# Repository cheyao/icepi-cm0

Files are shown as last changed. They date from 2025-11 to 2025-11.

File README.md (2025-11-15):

# Icepi CM0

A low-cost carrier board for the H3 CPU. It let's you have a cheap yet powerful Linux/Android device on your hand.



## Features

- H3 Processor
    - Quad-Core ARM Cortex-A7 @ 1.296GHz
    - ARM Mali400 MP2 OpenGL ES 2.0
- 512MiB of DDR3 RAM
- Ethernet PHY
- WiFi & Bluetooth
- GPDI
- Raspberry-pi compatiable GPIO
- USB connectors:
    - 2x USB-A 
    - 2x USB-C with one OTG
    - 1x USB-C 100W PD
- 3.5mm audio jack
- SD card slot
- eMMC 5.1 storage



More info coming soon!

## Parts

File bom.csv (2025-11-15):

Item | Price | Link
PCB + PCBA | 463.24$ | https://jlcpcb.com/
Heatsink | 6.74$ | https://fr.aliexpress.com/item/1005009710858892.html
Total | 469.98$

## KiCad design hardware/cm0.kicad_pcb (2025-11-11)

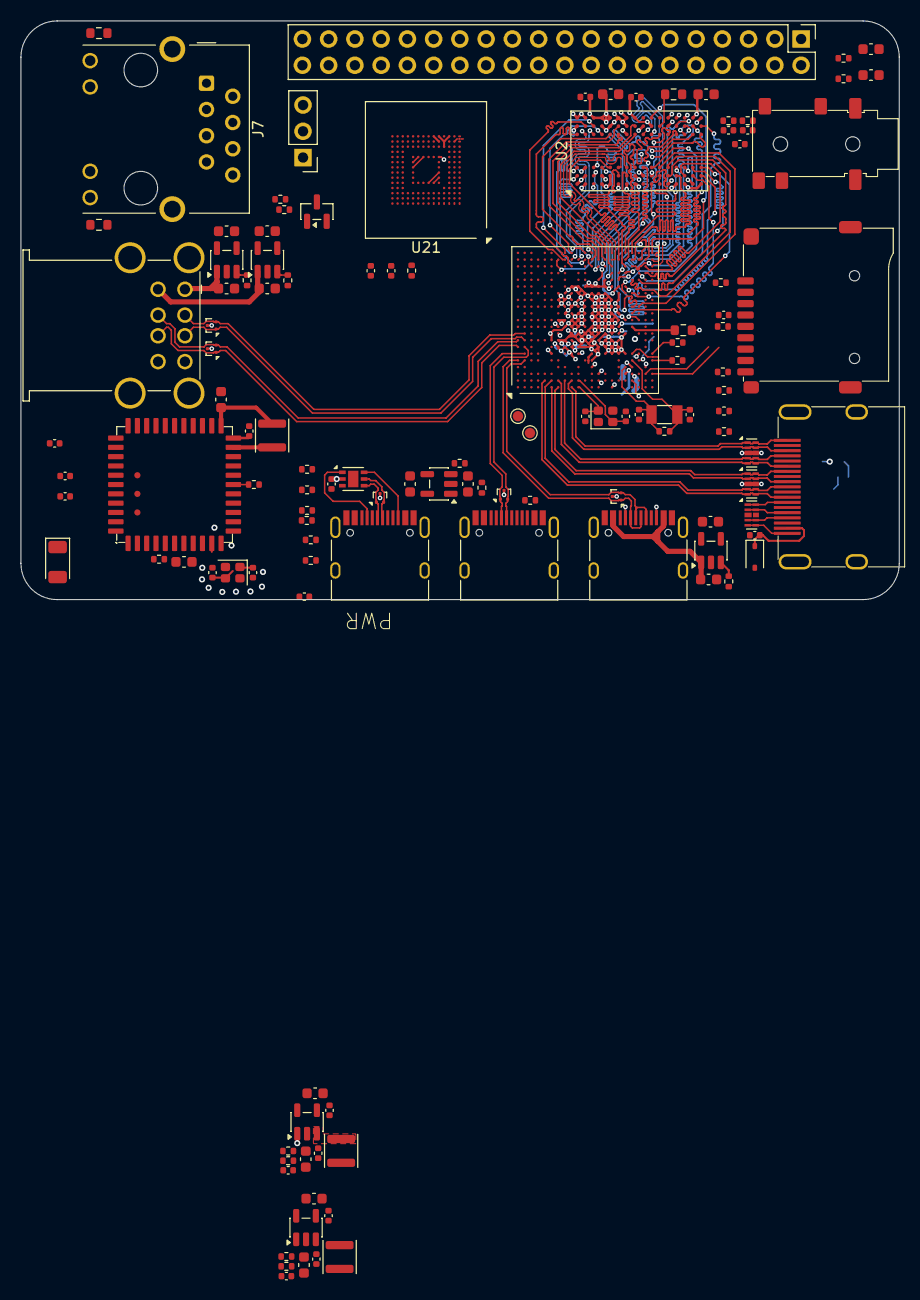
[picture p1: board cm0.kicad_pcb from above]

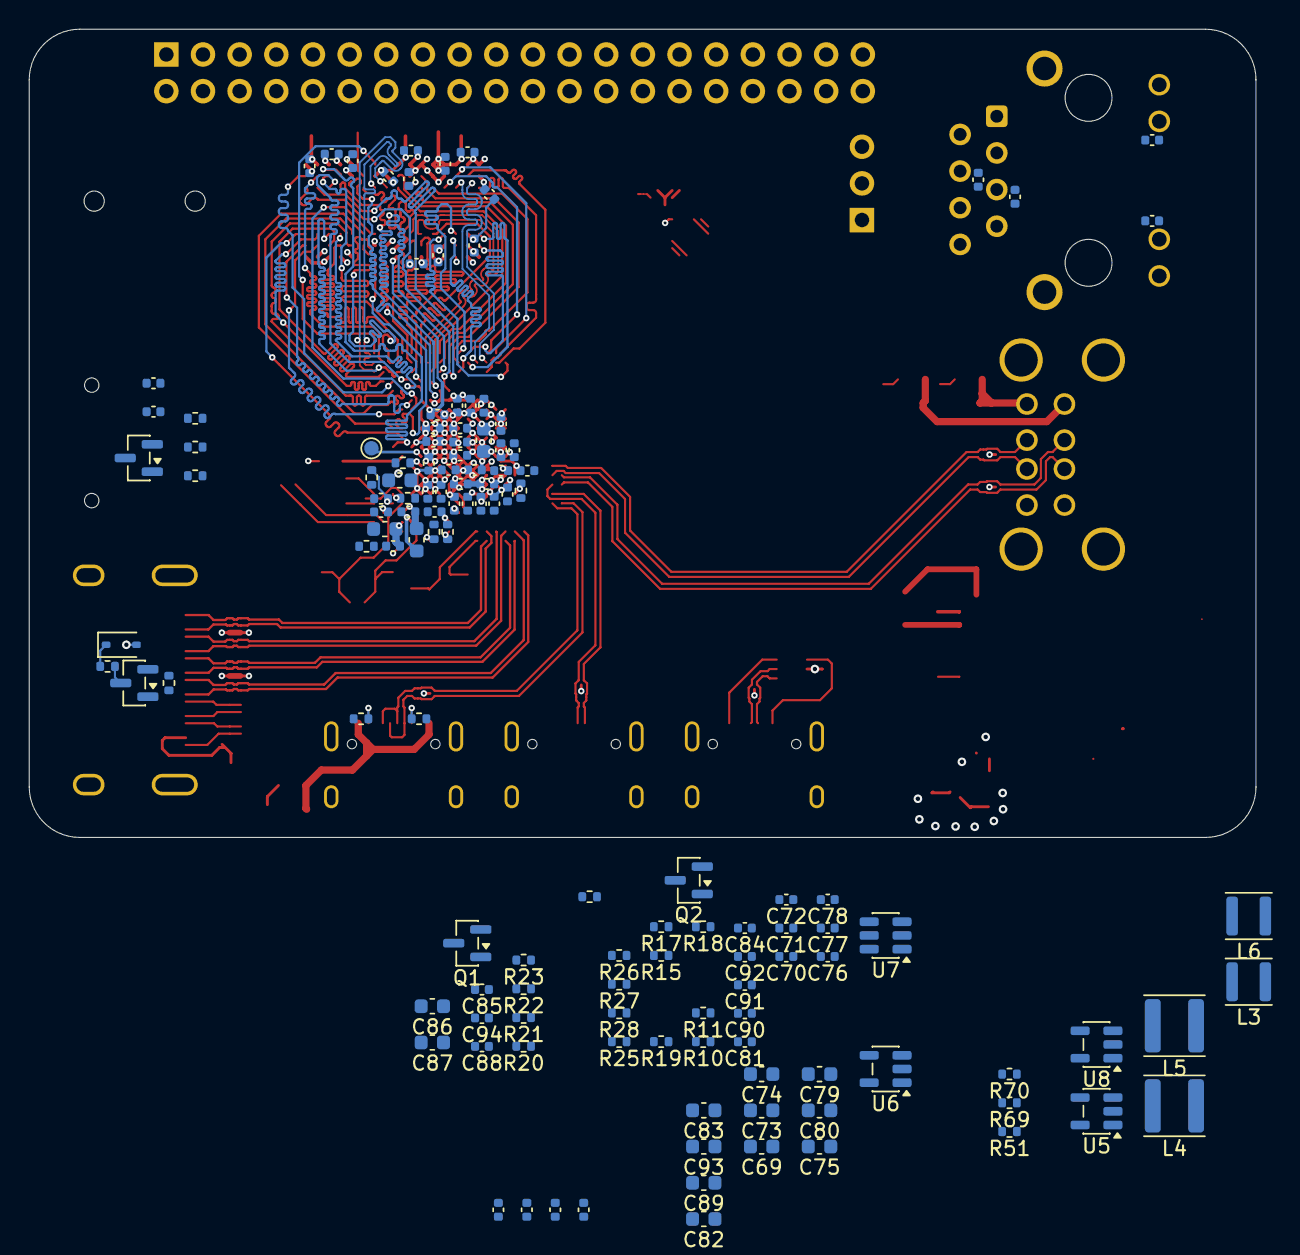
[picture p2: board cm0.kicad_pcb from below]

Board: 4 copper layers, 85.0 x 56.0 mm, 252 parts (129 on the bottom side), 209 nets.

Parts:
AE1: 2450AT18A100E; Johanson_2450AT18x100
C1, C2, C3, C4, C7, C8, C9, C12, C14, C18, C19, C23, C24, C26, C27, C29, C31, C37, C38, C40, C41, C42, C43, C46, C47, C48, C49, C52, C53, C54, C55, C56, C57, C58, C60, C62, C65, C67, C70, C72, C76, C78, C81, C84, C85, C90, C92, C95, C98, C101, C104, C108, C110, C113, C114, C121, C122, C123, C124, C130: 100nF; C_0402_1005Metric
C10, C11, C32, C129: 4.7uF; C_0402_1005Metric
C13, C16, C17, C21, C22, C25, C33, C35, C36, C45, C51, C107, C109, C111: 1uF; C_0402_1005Metric
C15, C20, C28, C30, C44, C50, C63, C64, C68, C69, C73, C74, C79, C83, C86, C89, C96, C97, C99, C100, C102, C103, C105, C106, C112, C118, C125, C126: 10uF; C_0603_1608Metric
C34, C39, C127, C128: 15pF; C_0402_1005Metric
C59, C75, C80, C82, C87, C93: 22uF; C_0603_1608Metric
C61, C66, C71, C77, C88, C91: 22pF; C_0402_1005Metric
C94, C116, C117: NC; C_0402_1005Metric
C115, C119, C120: 10pF; C_0402_1005Metric
D1, D2: 1N5819WS; D_SOD-323
J1: USB_A_Stacked; USB_A_SHOUHAN_AF_SS-JB17.6_Horizontal_Stacked
J2, J3, J4: USB_C_Receptacle_USB2.0_14P; USB_C_Receptacle_HRO_TYPE-C-31-M-12
J5: GPDI_A; GPDI_A_XUNPU_001S
J6: Micro_SD_Card_Det1; microSD_TF-01A
J7: RJ45_Hanrun_HR913550A_Horizontal; RJ45_Hanrun_HR911105A_Horizontal
J8: Conn_01x03; PinHeader_1x03_P2.54mm_Vertical
J9: Conn_02x20_Odd_Even; PinHeader_2x20_P2.54mm_Vertical
J10: AudioJack_PJ-342; Jack_3.5mm_SHOUHAN_PJ-342
L1, L2, L3, L6, L7: 2.2uH; L_Sunlord_SWPA3015S
L4, L5: 2.2uH; L_Sunlord_SWPA4030S
Q1, Q3, Q4: BSN20; SOT-23
Q2: AO3415A; SOT-23
Q5: MMBT3904; SOT-23
R1: 6.04k; R_0402_1005Metric
R2, R9, R54, R55: 240; R_0603_1608Metric
R3, R5, R24: 0; R_0402_1005Metric
R4: 220k; R_0402_1005Metric
R6: 10M; R_0402_1005Metric
R7, R8, R39, R40: 2k; R_0402_1005Metric
R10, R11, R12, R15, R16, R20, R23, R25, R31, R32, R33, R36, R41, R45, R51, R56, R63, R64, R65: 10k; R_0402_1005Metric
R13, R17, R26: 2.2k; R_0402_1005Metric
R14: 15k; R_0402_1005Metric
R18, R19, R27, R52, R62, R69, R70: 100k; R_0402_1005Metric
R21: 11.8K; R_0402_1005Metric
R22, R28, R37, R38, R46, R47, R48, R49, R50: 33k; R_0402_1005Metric
R29, R30, R34, R35, R42, R43: 56k; R_0402_1005Metric
R44, R53, R57, R58, R59, R60: 33; R_0402_1005Metric
R61, R66, R67, R68: 47k; R_0402_1005Metric
TP1, TP2, TP3: TestPoint; TestPoint_Pad_D1.0mm
U1: H3; FBGA-347_14x14mm_Layout21x21_P0.65mm
U2: H5TQ4G63EFR; FBGA-96_7.5x13mm_Layout9x16_P0.8mm
U3, U4, U5, U8: SY8088; SOT-23-5
U6: SY8089A; SOT-23-5
U7: SY8113; TSOT-23-6
U9, U10, U11, U12: SY6280AAC; SOT-23-5
U13, U14, U15, U16, U18: TPD2EUSB30; Texas_DRT-3
U17: HUSB237; DFN-6-1EP_2x2mm_P0.65mm_EP1x1.6mm
U19, U20, U23: UCL0524P; Diodes_UDFN-10_1.0x2.5mm_P0.5mm
U21: EMMC5.1_BGA153; LFBGA-153_11.5x13mm_Layout14x14_P0.5mm
U22: AP6212
Y1: 32kHz; Crystal_SMD_3215-2Pin_3.2x1.5mm
Y2: 26MHz; Crystal_SMD_2016-4Pin_2.0x1.6mm
Y3: 24MHz; Crystal_SMD_2016-4Pin_2.0x1.6mm

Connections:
+1V1_CPUX: C15.1, C16.2, C17.2, C18.2, C19.2, C85.2, C86.1, C87.1, L5.2, U1.N8 (VDD-CPUX), U1.P6 (VDD-CPUX), U1.P7 (VDD-CPUX), U1.P8 (VDD-CPUX), U1.P9 (VDD-CPUX), U1.R6 (VDD-CPUX), U1.R7 (VDD-CPUX), U1.R8 (VDD-CPUX), U1.T6 (VDD-CPUX), U1.T7 (VDD-CPUX), U1.T8 (VDD-CPUX), U1.U6 (VDD-CPUX), U1.U9 (VDD-CPUX)
+1V2_SYSTEM: C4.2, C20.1, C21.2, C22.2, C23.2, C24.2, C77.1, C78.2, C79.1, C80.1, L4.2, R18.2, U1.F8 (EPHY_VDD), U1.H10 (VDD-SYS), U1.J10 (VDD-SYS), U1.J11 (VDD-SYS), U1.J12 (VDD-SYS), U1.K10 (VDD-SYS), U1.K11 (VDD-SYS), U1.K12 (VDD-SYS), U1.L10 (VDD-SYS), U1.L11 (VDD-SYS), U1.L12 (VDD-SYS), U1.L13 (VDD-SYS), U1.L14 (VDD-SYS)
+1V5: C35.2, C36.2, C37.2, C38.2, C42.1, C44.1, C45.2, C46.1, C47.1, C48.1, C49.1, C50.1, C51.2, C52.1, C53.1, C54.1, C55.1, C56.1, C57.1, C58.1, C66.1, C67.2, C68.1, L2.2, R7.2, R14.2, U1.L16 (VCC-DRAM), U1.M16 (VCC-DRAM), U1.N16 (VCC-DRAM), U1.P16 (VCC-DRAM), U1.P17 (VCC-DRAM), U1.R16 (VCC-DRAM), U1.T12 (VCC-DRAM), U1.T13 (VCC-DRAM), U1.T14 (VCC-DRAM), U1.T15 (VCC-DRAM), U1.U11 (VCC-DRAM), U2.A1 (VDDQ), U2.A8 (VDDQ), U2.B2 (VDD), U2.C1 (VDDQ), U2.C9 (VDDQ), U2.D2 (VDDQ), U2.D9 (VDD), U2.E9 (VDDQ), U2.F1 (VDDQ), U2.G7 (VDD), U2.H2 (VDDQ), U2.H9 (VDDQ), U2.K2 (VDD), U2.K8 (VDD), U2.N1 (VDD), U2.N9 (VDD), U2.R1 (VDD), U2.R9 (VDD)
+3V3: C109.2, D1.2 (A), J6.4 (VDD), Q3.1 (G), Q4.1 (G), R37.1, R41.1, R42.1, R43.1, R54.1, R55.1, R56.1, U21.C6 (VCCQ), U21.E6 (VCC), U21.F5 (VCC), U21.J10 (VCC), U21.K9 (VCC), U21.M4 (VCCQ), U21.N4 (VCCQ), U21.P3 (VCCQ), U21.P5 (VCCQ)
+3V3_AVCC: C7.2, C12.2, C27.2, C28.1, C29.2, C71.1, C72.2, C73.1, C74.1, L3.2, Q2.2 (S), R10.1, R11.1, R15.2, R23.1, R61.1, R62.1, R65.1, R66.1, R68.1, U1.G9 (V33_TV), U1.K6 (VCC_RTC), U1.N3 (VCC_PLL), U1.V3 (AVCC)
+3V3_IO: C1.2, C2.2, C3.2, C8.2, C13.2, C14.2, C91.1, C92.2, C93.1, C129.1, L6.2, R25.2, R67.1, U1.G7 (EPHY_VCC), U1.G11 (VCC_USB), U1.G13 (VCC-IO), U1.G14 (VCC-IO), U1.G15 (VCC-IO), U1.H7 (VCC-PG), U1.H11 (VDD-EFUSEEBP), U1.H13 (VCC-IO), U1.H14 (VCC-IO), U1.J6 (GPDI_VCC), U1.J14 (VCC-IO), U1.J15 (VCC_PD)
+3V3_WIFI: C61.1, C62.2, C63.1, C112.1, C113.1, C114.1, L1.2, R12.2, R45.1, R46.1, R47.1, R48.1, R49.1, R50.1, R51.1, U22.9 (VBAT), U22.22 (VDDIO)
+5V: C59.1, C60.2, C64.1, C65.2, C69.1, C70.2, C75.1, C76.2, C82.1, C83.1, C84.2, C89.1, C90.2, C97.1, C100.1, C103.1, C106.1, C107.2, D2.2 (A), J4.A4 (VBUS), J4.A9 (VBUS), J4.B4 (VBUS), J4.B9 (VBUS), R39.2, R40.2, U3.1 (EN), U3.4 (IN), U4.4 (IN), U5.1 (EN), U5.4 (IN), U6.4 (IN), U7.5 (IN), U8.4 (IN), U9.4 (EN), U9.5 (IN), U10.4 (EN), U10.5 (IN), U11.4 (EN), U11.5 (IN), U12.4 (EN), U12.5 (IN), U17.2 (VBUS)
/Audio/AUDIO_L: C126.2, U1.AA3 (LINEOUTL)
/Audio/AUDIO_R: C125.2, U1.Y3 (LINEOUTR)
/DDR3/A0: U1.T17 (SA0), U2.N3 (A0)
/DDR3/A1: U1.U18 (SA1), U2.P7 (A1)
/DDR3/A2: U1.V19 (SA2), U2.P3 (A2)
/DDR3/A3: U1.V20 (SA3), U2.N2 (A3)
/DDR3/A4: U1.V21 (SA4), U2.P8 (A4)
/DDR3/A5: U1.Y19 (SA5), U2.P2 (A5)
/DDR3/A6: U1.Y20 (SA6), U2.R8 (A6)
/DDR3/A7: U1.V15 (SA7), U2.R2 (A7)
/DDR3/A8: U1.W18 (SA8), U2.T8 (A8)
/DDR3/A9: U1.Y18 (SA9), U2.R3 (A9)
/DDR3/A10: U1.P19 (SA10), U2.L7 (A10/AP)
/DDR3/A11: U1.N19 (SA11), U2.R7 (A11)
/DDR3/A12: U1.R18 (SA12), U2.N7 (A12/~BC)
/DDR3/A13: U1.V12 (SA13), U2.T3 (A13)
/DDR3/A14: U1.N17 (SA14), U2.T7 (A14)
/DDR3/A15: U1.R17 (SA15), U2.M7 (A15)
/DDR3/BA0: U1.W17 (SBA0), U2.M2 (BA0)
/DDR3/BA1: U1.T18 (SBA1), U2.N8 (BA1)
/DDR3/BA2: U1.V17 (SBA2), U2.M3 (BA2)
/DDR3/CKE: U1.AA21 (SCKE0), U2.K9 (CKE)
/DDR3/CLK+: U1.AA19 (SCK), U2.J7 (CK)
/DDR3/CLK-: U1.AA20 (SCKB), U2.K7 (~CK)
/DDR3/DQ0: U1.T20 (SDQ5), U2.E3 (DQ0)
/DDR3/DQ1: U1.P20 (SDQ2), U2.F7 (DQ1)
/DDR3/DQ2: U1.U19 (SDQ6), U2.F2 (DQ2)
/DDR3/DQ3: U1.N20 (SDQ0), U2.F8 (DQ3)
/DDR3/DQ4: U1.U20 (SDQ7), U2.H3 (DQ4)
/DDR3/DQ5: U1.P21 (SDQ1), U2.H8 (DQ5)
/DDR3/DQ6: U1.U21 (SDQ3), U2.G2 (DQ6)
/DDR3/DQ7: U1.R19 (SDQ4), U2.H7 (DQ7)
/DDR3/DQ8: U1.J21 (SDQ11), U2.D7 (DQ8)
/DDR3/DQ9: U1.M21 (SDQ14), U2.C3 (DQ9)
/DDR3/DQ10: U1.H21 (SDQ10), U2.C8 (DQ10)
/DDR3/DQ11: U1.M19 (SDQ15), U2.C2 (DQ11)
/DDR3/DQ12: U1.J19 (SDQ8), U2.A7 (DQ12)
/DDR3/DQ13: U1.L21 (SDQ13), U2.A2 (DQ13)
/DDR3/DQ14: U1.H20 (SDQ9), U2.B8 (DQ14)
/DDR3/DQ15: U1.L20 (SDQ12), U2.A3 (DQ15)
/DDR3/DQM0: U1.M20 (SDQM0), U2.E7 (LDM)
/DDR3/DQM1: U1.G20 (SDQM1), U2.D3 (UDM)
/DDR3/DQS0+: U1.R20 (SDQS0), U2.F3 (LDQS)
/DDR3/DQS0-: U1.R21 (SDQS0B), U2.G3 (~LDQS)
/DDR3/DQS1+: U1.K20 (SDQS1), U2.C7 (UDQS)
/DDR3/DQS1-: U1.J20 (SDQS1B), U2.B7 (~UDQS)
/DDR3/ODT: U1.W11 (SODT0), U2.K1 (ODT)
/DDR3/~CAS: U1.U15 (SCAS), U2.K3 (~CAS)
/DDR3/~CS: U1.W20 (SCS0), U2.L2 (~CS)
/DDR3/~RAS: U1.V13 (SRAS), U2.J3 (~RAS)
/DDR3/~RESET: U1.U16 (SRST), U2.T2 (~RESET)
/DDR3/~WE: U1.W13 (SWE), U2.L3 (~WE)
/GPDI/GPDI_CEC: Q3.2 (S), R37.2, U1.G5 (GPDI_CEC)
/GPDI/GPDI_CECI: J5.13 (CEC), Q3.3 (D), R38.2, U23.1, U23.10
/GPDI/GPDI_CLK+: J5.10 (CK+), U1.F2 (GPDI_CLK+), U20.4, U20.7
/GPDI/GPDI_CLK-: J5.12 (CK-), U1.E2 (GPDI_CLK-), U20.5, U20.6
/GPDI/GPDI_D0+: J5.7 (D0+), U1.G1 (GPDI_D0+), U20.1, U20.10
/GPDI/GPDI_D0-: J5.9 (D0-), U1.F1 (GPDI_D0-), U20.2, U20.9
/GPDI/GPDI_D1+: J5.4 (D1+), U1.H2 (GPDI_D1+), U19.4, U19.7
/GPDI/GPDI_D1-: J5.6 (D1-), U1.G2 (GPDI_D1-), U19.5, U19.6
/GPDI/GPDI_D2+: J5.1 (D2+), U1.J1 (GPDI_D2+), U19.1, U19.10
/GPDI/GPDI_D2-: J5.3 (D2-), U1.J2 (GPDI_D2-), U19.2, U19.9
/GPDI/GPDI_HPD: J5.19 (HPD), U1.M2 (GPDI_HPD), U23.5, U23.6
/GPDI/GPDI_SCL: J5.15 (SCL), R40.1, U1.H3 (GPDI_SCL), U23.2, U23.9
/GPDI/GPDI_SDA: J5.16 (SDA), R39.1, U1.K3 (GPDI_SDA), U23.4, U23.7
/GPIO/CPU_RX: R57.1, U1.H6 (PA5)
/GPIO/CPU_TX: R58.1, U1.F5 (PA4)
/H3/AGND: C28.2, C29.1, C30.2, C31.1, C32.2, C33.1, R4.2, R5.1, U1.U3 (AGND)
/H3/BT_HOST_WAKE: U1.P2 (PL2), U22.7 (BT_HOST_WAKE)
/H3/BT_RXD: U1.D3 (UART1_RX), U22.43 (UART_RXD)
/H3/BT_TXD: U1.G4 (UART1_TX), U22.42 (UART_TXD)
/H3/BT_WAKE: R45.2, R69.1, U1.A13 (PA20), U22.6 (BT_WAKE)
/H3/EPHY_LINK_LED: C124.1, J7.10, U1.A2 (EPHY_LINK_LED)
/H3/EPHY_RX+: J7.3 (RD+), U1.B4 (EPHY_RXP)
/H3/EPHY_RX-: J7.6 (RD-), U1.A4 (EPHY_RXN)
/H3/EPHY_SPD_LED: C123.1, J7.11, U1.F7 (EPHY_SPD_LED)
/H3/EPHY_TX+: J7.1 (TD+), U1.B3 (EPHY_TXP)
/H3/EPHY_TX-: J7.2 (TD-), U1.A3 (EPHY_TXN)
/H3/KEYADC: R62.2, U1.AA5 (KEYADC)
/H3/PWR_CPUFB: C88.1, R20.1, TP1.1, U1.T10 (VDD-CPUFB)
/H3/PWR_DRAM: R10.2, U1.M6 (PL9), U4.1 (EN)
/H3/PWR_IO: Q2.1 (G), R27.2, U1.R2 (PL5)
/H3/PWR_KEY: R66.2, U1.R1 (PL3)
/H3/PWR_SYSTEM: R11.2, U1.T2 (PL8), U6.1 (EN), U7.4 (EN)
/H3/PWR_VSET: R24.2, U1.T4 (PL6)
/H3/RECOVERY: R68.2, U1.N2 (PL4)
/H3/RESET: C130.2, Q5.3 (C), R65.2, U1.V6 (RESET)
/H3/SDIO_CLK: R53.1, U1.J3 (SDC1_CLK)
/H3/SDIO_CMD: R50.2, U1.L2 (SDC1_CMD), U22.16 (SDIO_DATA_CMD)
/H3/SDIO_D0: R49.2, U1.H4 (SDC1_D0), U22.18 (SDIO_DATA_0)
/H3/SDIO_D1: R48.2, U1.F3 (SDC1_D1), U22.19 (SDIO_DATA_1)
/H3/SDIO_D2: R47.2, U1.C2 (SDC1_D2), U22.14 (SDIO_DATA_2)
/H3/SDIO_D3: R46.2, U1.C1 (SDC1_D3), U22.15 (SDIO_DATA_3)
/H3/SD_CLK: R44.1, U1.D20 (PF2)
/H3/SD_CMD: J6.3 (CMD), R42.2, U1.F18 (PF3)
/H3/SD_D0: J6.7 (DAT0), U1.A19 (PF1)
/H3/SD_D1: J6.8 (DAT1), U1.D19 (PF0)
/H3/SD_D2: J6.1 (DAT2), U1.C20 (PF5)
/H3/SD_D3: J6.2 (DAT3/CD), U1.E21 (PF4)
/H3/SD_DET: J6.9 (DET), R43.2, U1.G18 (PF6)
/H3/UBOOT: R67.2, U1.W6 (UBOOT)
/H3/USB_D0+: J2.A7 (D-), J2.B7 (D-), U1.A5 (USB_D0+), U13.1 (D+)
/H3/USB_D0-: J2.A6 (D+), J2.B6 (D+), U1.B5 (USB_D0-), U13.2 (D-)
/H3/USB_D1+: J3.A7 (D-), J3.B7 (D-), U1.B6 (USB_D1+), U15.1 (D+)
/H3/USB_D1-: J3.A6 (D+), J3.B6 (D+), U1.B7 (USB_D1-), U15.2 (D-)
/H3/USB_D2+: J1.7 (D2+), U1.A7 (USB_D2+), U14.1 (D+)
/H3/USB_D2-: J1.6 (D2-), U1.A8 (USB_D2-), U14.2 (D-)
/H3/USB_D3+: J1.3 (D1+), U1.B8 (USB_D3+), U16.1 (D+)
/H3/USB_D3-: J1.2 (D1-), U1.B9 (USB_D3-), U16.2 (D-)
/H3/VRA1: C33.2, U1.Y4 (VRA1)
/H3/VRA2: C32.1, R4.1, U1.W5 (VRA2)
/H3/VRP: C30.1, C31.2, U1.V4 (VRP)
/H3/WIFI_32K: R51.2, U1.P3 (X32KFOUT), U22.24 (LPO)
/H3/WL_HOST_WAKE: U1.T3 (PL7), U22.13 (WL_HOST_WAKE)
/H3/WL_REG_ON: R52.1, U1.F13 (PA8), U22.12 (WL_REG_ON)
/H3/X24MI: C127.1, U1.K2 (X24MIN), Y3.2
/H3/X24MO: C128.1, U1.K1 (X24MOUT), Y3.4
/H3/X32KI: C34.1, R6.1, U1.V5 (X32KIN), Y1.2
/H3/X32KO: C39.1, R6.2, U1.U4 (X32KOUT), Y1.1
/H3/eMMC_CLK: U1.A17 (PC5), U21.M6 (CLK)
/H3/eMMC_CMD: R41.2, U1.E16 (PC6), U21.M5 (CMD)
/H3/eMMC_D0: U1.B18 (PC8), U21.A3 (DAT0)
/H3/eMMC_D1: U1.C17 (PC9), U21.A4 (DAT1)
/H3/eMMC_D2: U1.D17 (PC10), U21.A5 (DAT2)
/H3/eMMC_D3: U1.C18 (PC11), U21.B2 (DAT3)
/H3/eMMC_D4: U1.B17 (PC12), U21.B3 (DAT4)
/H3/eMMC_D5: U1.B19 (PC13), U21.B4 (DAT5)
/H3/eMMC_D6: U1.F17 (PC14), U21.B5 (DAT6)
/H3/eMMC_D7: U1.C19 (PC15), U21.B6 (DAT7)
/H3/~BT_CTS: U1.E3 (UART1_CTS), U22.44 (UART_CTS_N)
/H3/~BT_RST: R70.1, U1.D13 (PA9), U22.34 (BT_RST_N)
/H3/~BT_RTS: U1.C3 (UART1_RTS), U22.41 (UART_RTS_N)
/H3/~eMMC_RST: U1.H16 (PC16), U21.K5 (~RST)
/USB/PWR_CC1: J4.A5 (CC1), U17.1 (CC1)
/USB/PWR_CC2: J4.B5 (CC2), U17.6 (CC2)
/USB/PWR_D+: J4.A6 (D+), J4.B6 (D+), U17.4 (D+), U18.1 (D+)
/USB/PWR_D-: J4.A7 (D-), J4.B7 (D-), U17.5 (D-), U18.2 (D-)
/USB/USB_VBUS0: C95.2, C96.1, J2.A4 (VBUS), J2.A9 (VBUS), J2.B4 (VBUS), J2.B9 (VBUS), R29.1, R30.1, U9.1 (OUT)
/USB/USB_VBUS1: C104.2, C105.1, J3.A4 (VBUS), J3.A9 (VBUS), J3.B4 (VBUS), J3.B9 (VBUS), R34.1, R35.1, U12.1 (OUT)
/USB/USB_VBUS2: C98.2, C99.1, J1.1 (VBUS1), U10.1 (OUT)
/USB/USB_VBUS3: C101.2, C102.1, J1.5 (VBUS2), U11.1 (OUT)
GND: AE1.2 (Shield), C1.1, C2.1, C3.1, C4.1, C7.1, C8.1, C9.2, C10.2, C11.2, C12.1, C13.1, C14.1, C15.2, C16.1, C17.1, C18.1, C19.1, C20.2, C21.1, C22.1, C23.1, C24.1, C25.1, C26.1, C27.1, C34.2, C35.1, C36.1, C37.1, C38.1, C39.2, C40.2, C41.2, C43.2, C44.2, C45.1, C46.2, C47.2, C48.2, C49.2, C50.2, C51.1, C52.2, C53.2, C54.2, C55.2, C56.2, C57.2, C58.2, C59.2, C60.1, C62.1, C63.2, C64.2, C65.1, C67.1, C68.2, C69.2, C70.1, C75.2, C76.1, C78.1, C79.2, C80.2, C82.2, C83.2, C84.1, C85.1, C86.2, C87.2, C89.2, C90.1, C92.1, C93.2, C94.2, C95.1, C96.2, C97.2, C98.1, C99.2, C100.2, C101.1, C102.2, C103.2, C104.1, C105.2, C106.2, C107.1, C108.1, C109.1, C110.2, C111.1, C112.2, C113.2, C114.2, C116.2, C117.2, C118.2, C119.2, C120.2, C121.1, C122.1, C123.2, C124.2, C127.2, C128.2, C130.1, J1.4 (GND1), J1.8 (GND2), J1.9 (Shield), J2.A1 (GND), J2.A12 (GND), J2.B1 (GND), J2.B12 (GND), J2.S1 (SHIELD), J3.A1 (GND), J3.A12 (GND), J3.B1 (GND), J3.B12 (GND), J3.S1 (SHIELD), J4.A1 (GND), J4.A12 (GND), J4.B1 (GND), J4.B12 (GND), J4.S1 (SHIELD), J5.2 (D2S), J5.5 (D1S), J5.8 (D0S), J5.11 (CKS), J5.17 (GND), J5.SH, J6.6 (VSS), J6.10 (SHIELD), J7.8, J7.SH, J8.3, J10.2, Q1.2 (S), Q5.2 (E), R1.2, R2.1, R3.2, R5.2, R8.1, R9.2, R13.1, R16.1, R17.1, R19.1, R21.2, R26.1, R27.1, R28.2, R31.2, R32.2, R33.2, R36.2, R52.2, R63.2, R69.2, R70.2, U1.A21 (GND), U1.AA1 (GND), U1.G8 (GND), U1.H8 (GND_TV), U1.H12 (GND), U1.H15 (GND), U1.J9 (GND), U1.J13 (GND), U1.J16 (GND), U1.K7 (GND), U1.K8 (GND), U1.K9 (GND), U1.K13 (GND), U1.K14 (GND), U1.K15 (GND), U1.K16 (GND), U1.L8 (GND), U1.L9 (GND), U1.L15 (GND), U1.M5 (GPDI_GND), U1.M7 (GND), U1.M8 (GND), U1.M9 (GND), U1.M10 (GND), U1.M11 (GND), U1.M12 (GND), U1.M13 (GND), U1.M14 (GND), U1.M15 (GND), U1.N7 (GND), U1.N9 (GND), U1.N10 (GND), U1.N11 (GND), U1.N12 (GND), U1.N13 (GND), U1.N14 (GND), U1.N15 (GND), U1.P10 (GND), U1.P11 (GND), U1.P12 (GND), U1.P13 (GND), U1.P14 (GND), U1.P15 (GND), U1.R9 (GND), U1.R10 (GND), U1.R11 (GND), U1.R12 (GND), U1.R13 (GND), U1.R14 (GND), U1.T11 (GND), U2.A9 (VSS), U2.B1 (VSSQ), U2.B3 (VSS), U2.B9 (VSSQ), U2.D1 (VSSQ), U2.D8 (VSSQ), U2.E1 (VSS), U2.E2 (VSSQ), U2.E8 (VSSQ), U2.F9 (VSSQ), U2.G1 (VSSQ), U2.G8 (VSS), U2.G9 (VSSQ), U2.J2 (VSS), U2.J8 (VSS), U2.M1 (VSS), U2.M9 (VSS), U2.P1 (VSS), U2.P9 (VSS), U2.T1 (VSS), U2.T9 (VSS), U3.2 (GND), U4.2 (GND), U5.2 (GND), U6.2 (GND), U7.2 (GND), U8.2 (GND), U9.2 (GND), U10.2 (GND), U11.2 (GND), U12.2 (GND), U13.3 (GND), U14.3 (GND), U15.3 (GND), U16.3 (GND), U17.3 (VSET), U17.7 (GND), U18.3 (GND), U19.3, U19.8, U20.3, U20.8, U21.A6 (VSS), U21.C4 (VSSQ), U21.E7 (VSS), U21.G5 (VSS), U21.H10 (VSS), U21.J5 (VSS), U21.K8 (VSSQ), U21.N2 (VSSQ), U21.N5 (VSSQ), U21.P4 (VSSQ), U21.P6 (VSSQ), U22.1 (GND), U22.3 (GND), U22.20 (GND), U22.31 (GND), U22.33 (GND), U22.36 (GND), U23.3, U23.8, Y2.2, Y2.4, Y3.1, Y3.3
unnamed: AE1.1 (A), C115.2, C116.1, C117.1
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

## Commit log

2025-10-28 Created own symbol, footprint and drew DDR3 schematic
    [cm0.kicad_pcb, cm0.kicad_sch, cpu.kicad_sch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]
2025-11-01 Added A13 line to DDR3
    [cm0.kicad_pcb, untitled.kicad_sch]
2025-11-03 Re-routed DDR3 on L4 & drew USB schematic
    [cm0.kicad_pcb, cm0.kicad_sch, cpu.kicad_sch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]
2025-11-06 Add eMMC and uSD
    [cm0.kicad_pcb, cm0.kicad_sch, cpu.kicad_sch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]
2025-11-11 Integrating DCDC converters
    [cm0.kicad_pcb, usb.kicad_sch]
2025-11-15 Finished with V1!
    [audio.kicad_sch, bom.csv, cm0.kicad_sch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]
2025-11-21 Add fixes and improvements
    [audio.kicad_sch, cm0.kicad_sch, cpu.kicad_sch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]
2026-01-09 Remove outdated schematic
